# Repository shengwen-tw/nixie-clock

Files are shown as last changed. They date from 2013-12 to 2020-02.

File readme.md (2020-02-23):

## Nixie Clock
* Author : Shengwen Cheng (shengwen1997.tw@gmail.com)
* Special thanks : 張世昌, 楊宗凡, 施翰誠, 周明哲, 王尹辰, 陳冠宇
* Microcontroller : Arduino (ATMega328p-au)

## Introduction

A Russian IN-14 Nixie tube clock which support time display, alram and mp3 playing function 

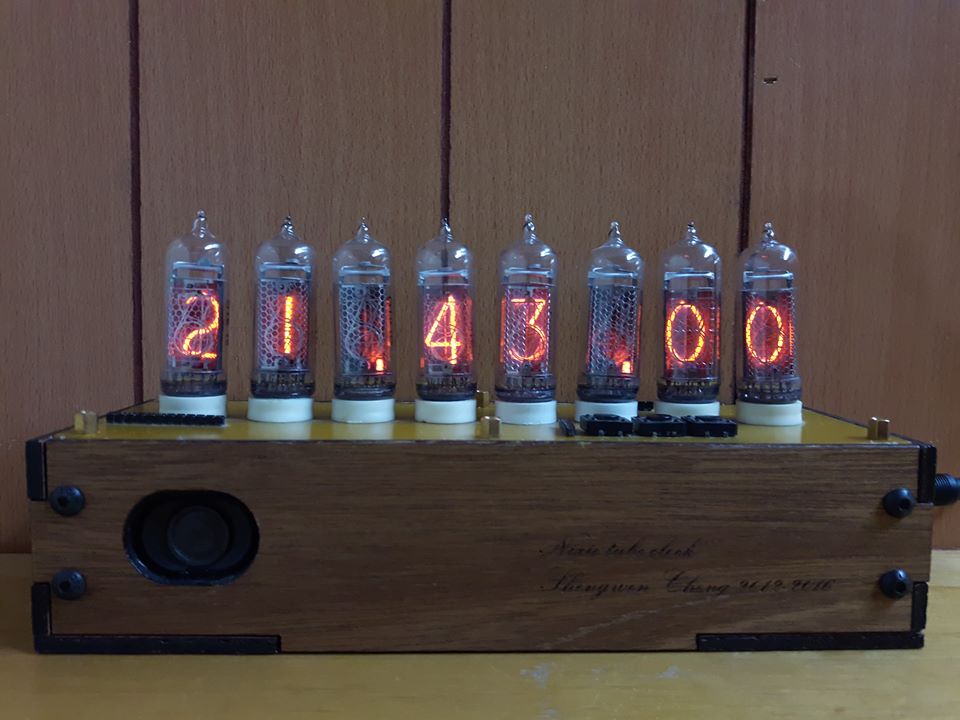
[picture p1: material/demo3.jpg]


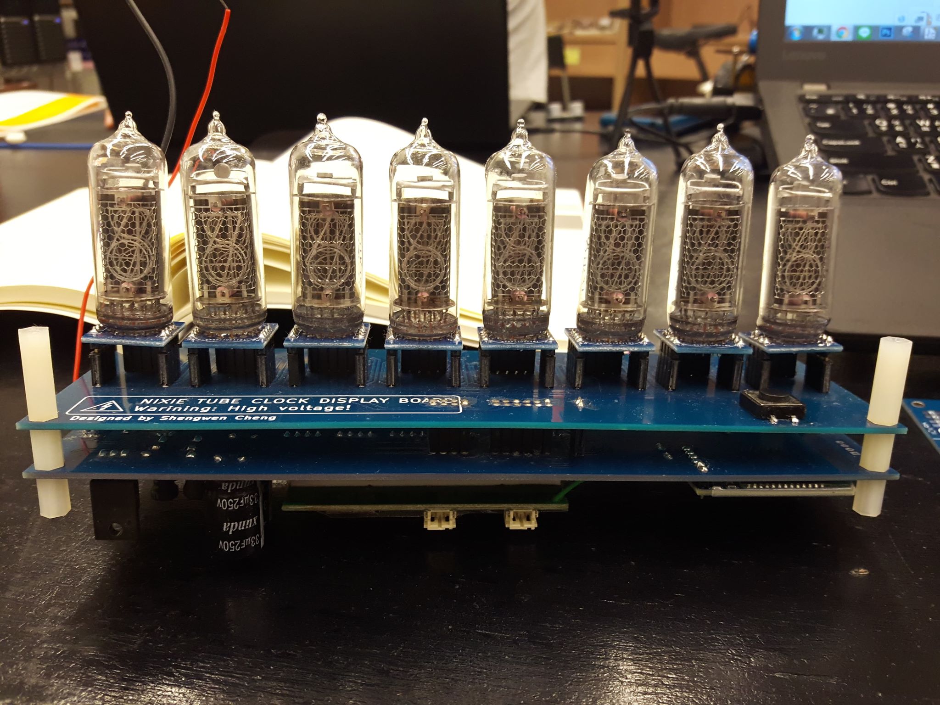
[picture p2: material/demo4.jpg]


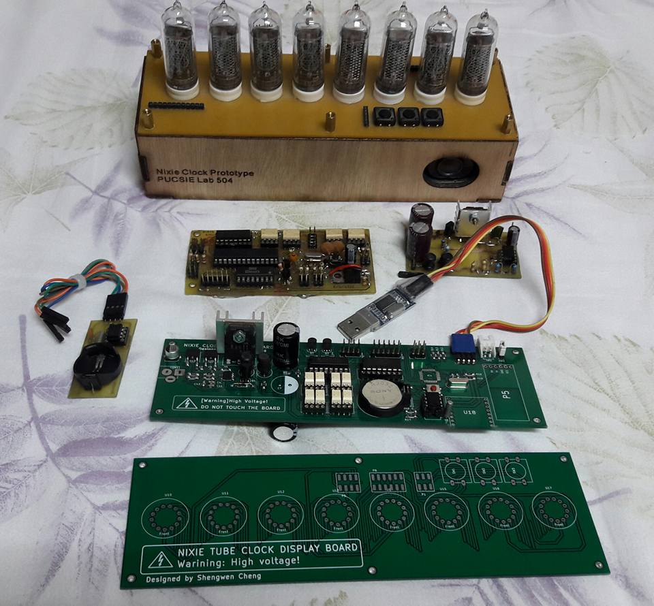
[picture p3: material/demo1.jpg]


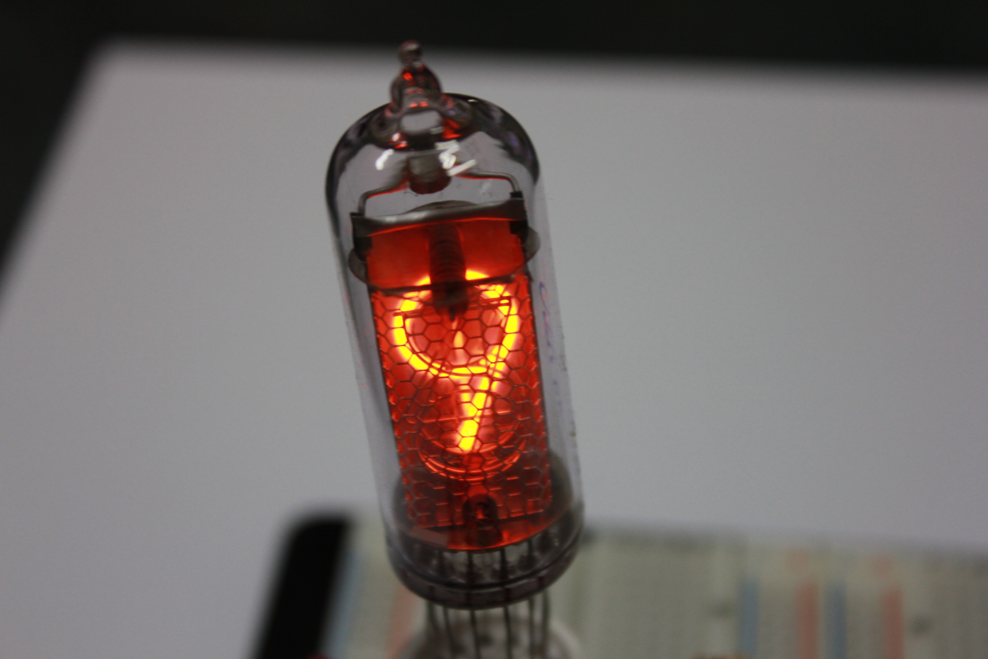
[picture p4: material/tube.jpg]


## Firmware dependencies

You must install the following arduino libraries before compiling the firmware (find the zip in firmware directory)

* DFPlayer driver (a modified version of AltSoftwareSerial)
* RTC and Time library

## USBasp driver

1. Download Zadig

2. Select **Options/List All Devices**

3. Select **USBasp**

4. Select **libusbK**

5. Click **Replace Driver**

## Circuit files

The hardware was designed under Kicad 4, any previous version may not work properly.

## BOM
read the [BOM.md](https://github.com/shengwen1997/Nixie-Clock/blob/master/BOM.md) for detailed information

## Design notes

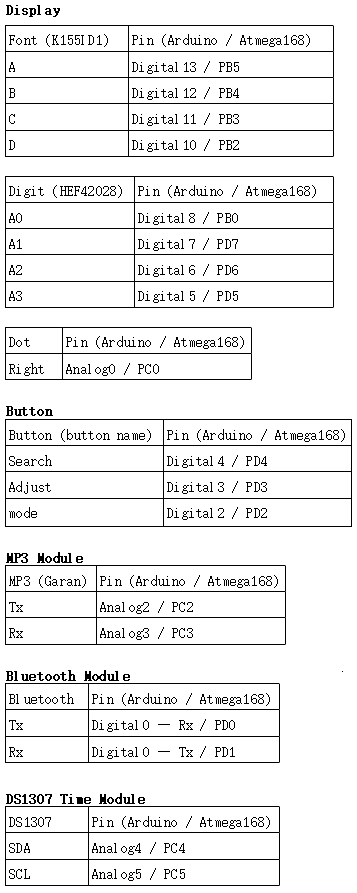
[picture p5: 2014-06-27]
material/pinout.png

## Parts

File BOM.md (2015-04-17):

Power Supply Board
======================

**Resistor**

0.5 ohm * 2

620 ohm * 3

760 ohm * 1

1k ohm * 2

100k ohm * 1

**Electrolytic capacitor**

100uf/16v * 1

33uf/250v * 2

**Mylar capacitor**

1500pf * 1

**Inductor**

22 uf * 1

220 uh * 1

**Diode**

1N4148 * 1

FR157 * 1

**IC**

MC34063A * 1

*BJT**

2SB647(PNP) * 1

**MOSFET**

2SK2611(N-Type) * 1

Display Board
======================

**Nixie tube**

IN-14 * 8

Control Board
======================

**Resistor**

330 ohm * 6

1.8k ohm * 2

4.7k ohm *2

10k ohm * 1

30k ohm * 1

**Electrolytic capacitor**

100uf/16v * 

**Ceramic capacitors**

0.1uf * 2

22pf * 2

**IC**

LM7805 * 1

ATMega328p * 1

TLP521 * 4

HEF428 * 1

K155ID1 * 1

**BJT**

MPSA9(PNP) * 3

**Quartz crystal oscillator**

16MHZ * 1

**Switch**

(2p, 6x6x4.3mm) * 1

**Pin**

(1 * 2 array) * 5

(1 * 4 array) * 2

(2 * 4 array) * 1

(2 * 6 array) * 1

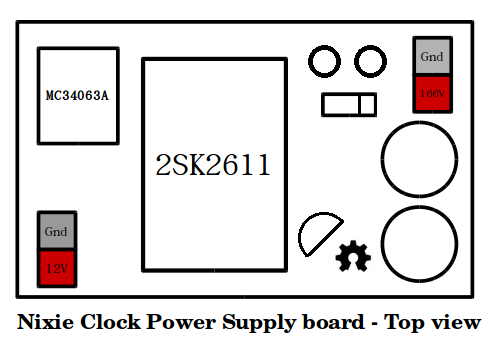
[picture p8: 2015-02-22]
material/power_supply_board.png

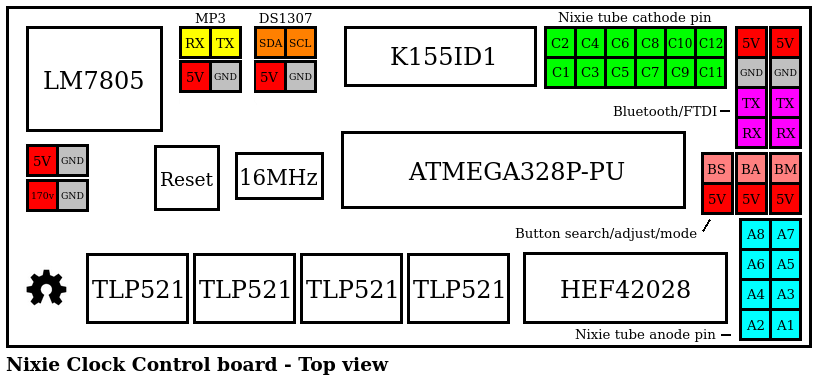
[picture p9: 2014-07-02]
material/control_board.png

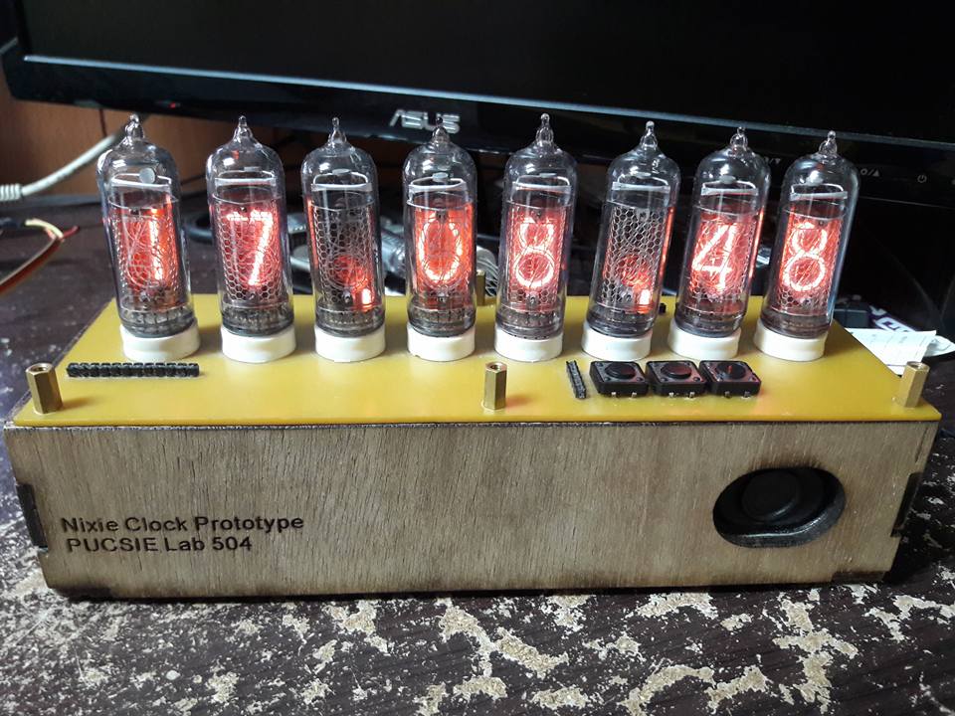
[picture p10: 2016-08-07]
material/demo2.jpg

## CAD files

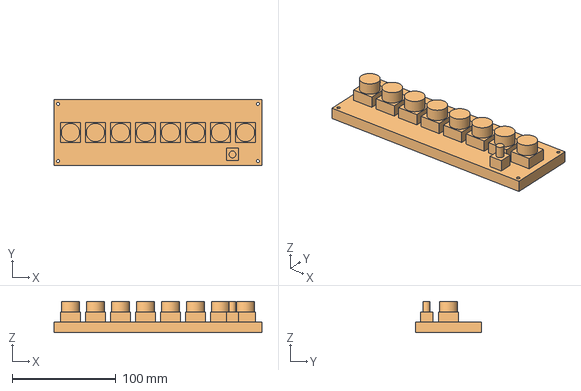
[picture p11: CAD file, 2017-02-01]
cad/obsoleted/cad.fcstd
200.0 x 63.0 x 30.0 mm

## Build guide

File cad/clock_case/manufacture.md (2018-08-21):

## Manufacture note

The case was designed by using **SketchUp**, a transformation from 3D to 2D is needed.

You can cut the case with laser cutter then assemble it with super glue and screws.

## Materials

4mm Plywood

M3 12mm SHCS * 8

M4 10mm SHCS * 8

M3 10mm female plastic pillar (top layer) * 4

M3 10mm male plastic pillar (second layer) * 4

M3 20mm female plastic pillar (bottom layer) * 4

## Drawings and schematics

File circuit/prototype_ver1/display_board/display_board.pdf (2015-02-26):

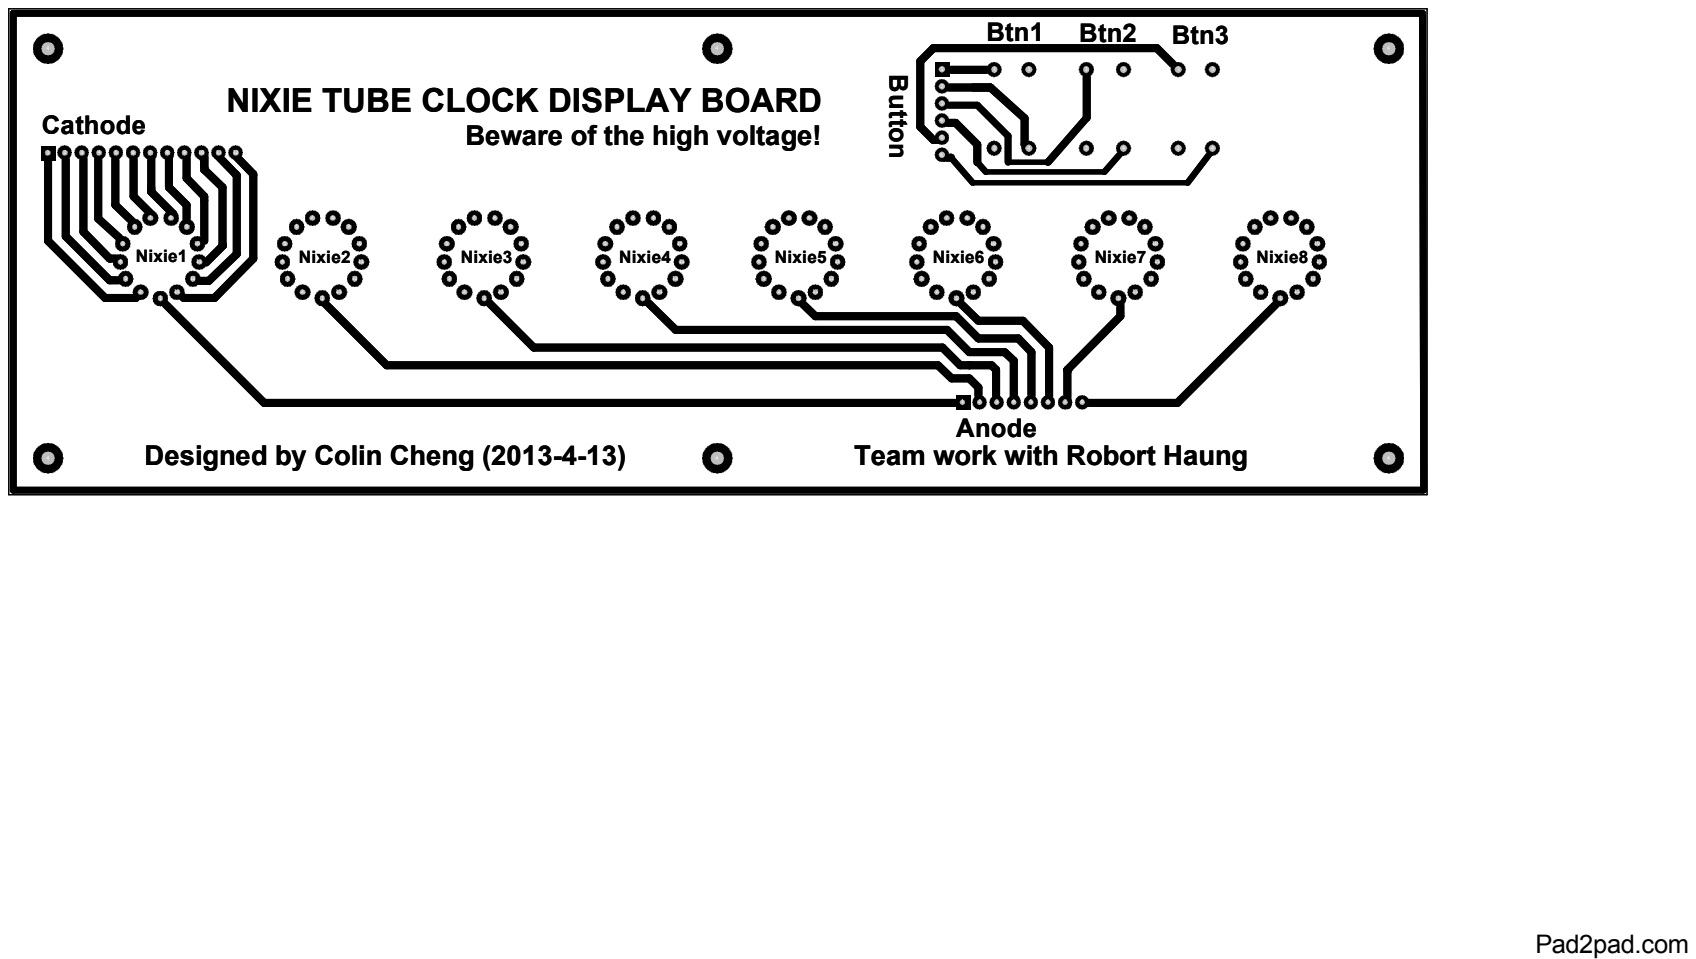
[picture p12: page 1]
Pad2pad.com; Designed by Colin Cheng (2013-4-13); Team work with Robort Haung; Btn1; Btn2; Btn3; B utto; Anode; Cathode; Nixie1; Nixie2; Nixie3; Nixie4; Nixie5; Nixie6; Nixie7; Nixie8

NIXIE TUBE CLOCK DISPLAY BOARD

Beware of the high voltage!

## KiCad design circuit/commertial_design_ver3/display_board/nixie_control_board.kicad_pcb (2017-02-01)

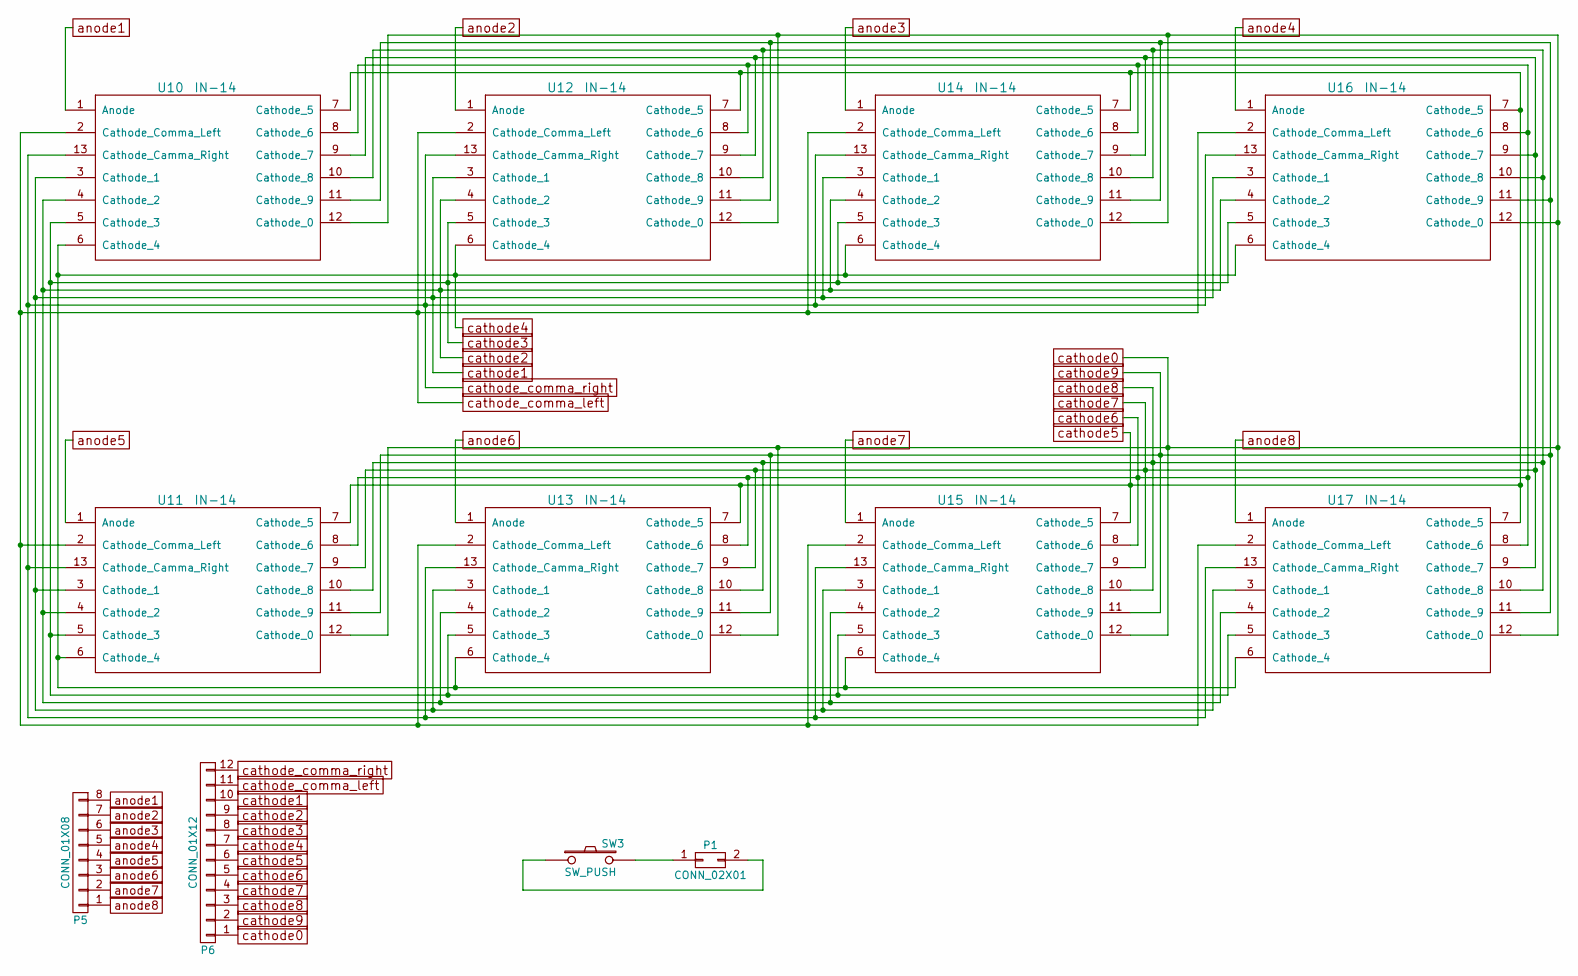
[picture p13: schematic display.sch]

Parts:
P1: CONN_02X01; Pin_Header_Straight_2x01
P5: CONN_01X08; Pin_Header_Straight_2x04
P6: CONN_01X12; Pin_Header_Straight_2x06
SW3: SW_PUSH; SW_PUSH-12mm
U10, U11, U12, U13, U14, U15, U16, U17: IN-14

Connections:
unnamed: P1.1, SW3.2
unnamed: P1.2, SW3.1
anode1: P5.8, U10.1 (Anode)
anode2: P5.7, U12.1 (Anode)
anode3: P5.6, U14.1 (Anode)
anode4: P5.5, U16.1 (Anode)
anode5: P5.4, U11.1 (Anode)
anode6: P5.3, U13.1 (Anode)
anode7: P5.2, U15.1 (Anode)
anode8: P5.1, U17.1 (Anode)
cathode0: P6.1, U10.12 (Cathode_0), U11.12 (Cathode_0), U12.12 (Cathode_0), U13.12 (Cathode_0), U14.12 (Cathode_0), U15.12 (Cathode_0), U16.12 (Cathode_0), U17.12 (Cathode_0)
cathode1: P6.10, U10.3 (Cathode_1), U11.3 (Cathode_1), U12.3 (Cathode_1), U13.3 (Cathode_1), U14.3 (Cathode_1), U15.3 (Cathode_1), U16.3 (Cathode_1), U17.3 (Cathode_1)
cathode2: P6.9, U10.4 (Cathode_2), U11.4 (Cathode_2), U12.4 (Cathode_2), U13.4 (Cathode_2), U14.4 (Cathode_2), U15.4 (Cathode_2), U16.4 (Cathode_2), U17.4 (Cathode_2)
cathode3: P6.8, U10.5 (Cathode_3), U11.5 (Cathode_3), U12.5 (Cathode_3), U13.5 (Cathode_3), U14.5 (Cathode_3), U15.5 (Cathode_3), U16.5 (Cathode_3), U17.5 (Cathode_3)
cathode4: P6.7, U10.6 (Cathode_4), U11.6 (Cathode_4), U12.6 (Cathode_4), U13.6 (Cathode_4), U14.6 (Cathode_4), U15.6 (Cathode_4), U16.6 (Cathode_4), U17.6 (Cathode_4)
cathode5: P6.6, U10.7 (Cathode_5), U11.7 (Cathode_5), U12.7 (Cathode_5), U13.7 (Cathode_5), U14.7 (Cathode_5), U15.7 (Cathode_5), U16.7 (Cathode_5), U17.7 (Cathode_5)
cathode6: P6.5, U10.8 (Cathode_6), U11.8 (Cathode_6), U12.8 (Cathode_6), U13.8 (Cathode_6), U14.8 (Cathode_6), U15.8 (Cathode_6), U16.8 (Cathode_6), U17.8 (Cathode_6)
cathode7: P6.4, U10.9 (Cathode_7), U11.9 (Cathode_7), U12.9 (Cathode_7), U13.9 (Cathode_7), U14.9 (Cathode_7), U15.9 (Cathode_7), U16.9 (Cathode_7), U17.9 (Cathode_7)
cathode8: P6.3, U10.10 (Cathode_8), U11.10 (Cathode_8), U12.10 (Cathode_8), U13.10 (Cathode_8), U14.10 (Cathode_8), U15.10 (Cathode_8), U16.10 (Cathode_8), U17.10 (Cathode_8)
cathode9: P6.2, U10.11 (Cathode_9), U11.11 (Cathode_9), U12.11 (Cathode_9), U13.11 (Cathode_9), U14.11 (Cathode_9), U15.11 (Cathode_9), U16.11 (Cathode_9), U17.11 (Cathode_9)
cathode_comma_left: P6.11, U10.2 (Cathode_Comma_Left), U11.2 (Cathode_Comma_Left), U12.2 (Cathode_Comma_Left), U13.2 (Cathode_Comma_Left), U14.2 (Cathode_Comma_Left), U15.2 (Cathode_Comma_Left), U16.2 (Cathode_Comma_Left), U17.2 (Cathode_Comma_Left)
cathode_comma_right: P6.12, U10.13 (Cathode_Camma_Right), U11.13 (Cathode_Camma_Right), U12.13 (Cathode_Camma_Right), U13.13 (Cathode_Camma_Right), U14.13 (Cathode_Camma_Right), U15.13 (Cathode_Camma_Right), U16.13 (Cathode_Camma_Right), U17.13 (Cathode_Camma_Right)

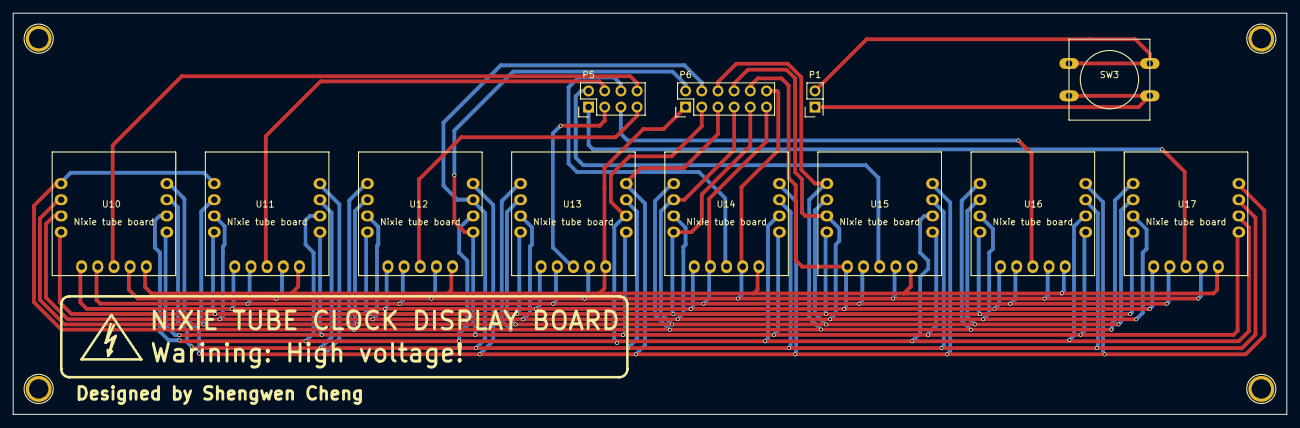
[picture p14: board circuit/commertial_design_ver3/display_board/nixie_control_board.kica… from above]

Board: 2 copper layers, 200.0 x 63.0 mm, 13 parts (0 on the bottom side), 22 nets.

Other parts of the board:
e REF**: 1pin

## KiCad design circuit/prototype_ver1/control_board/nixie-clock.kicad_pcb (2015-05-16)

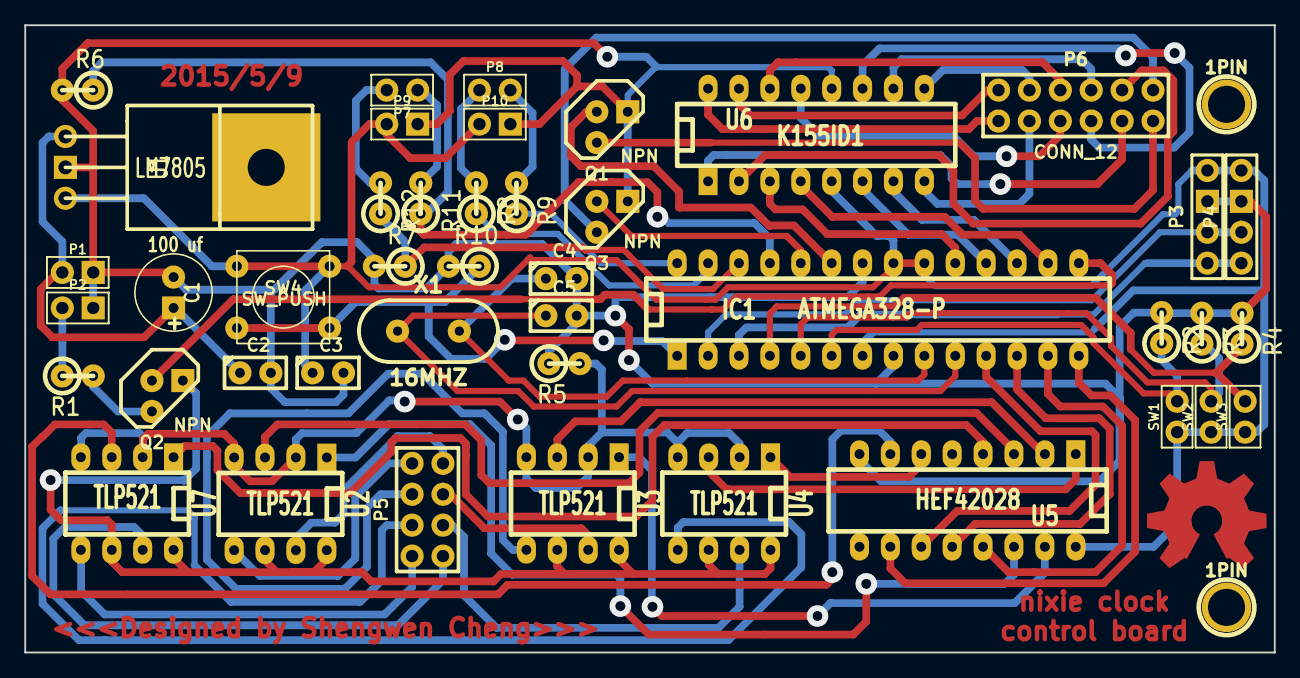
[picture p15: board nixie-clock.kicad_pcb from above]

Board: 2 copper layers, 102.7 x 51.6 mm, 46 parts (0 on the bottom side), 62 nets.

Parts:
1PIN, 1PIN#2: P***; 1pin
C1: 100 uf; C1V7
C2, C3: 0.1 uf; C1
C4, C5: 22pf; C1
IC1: ATMEGA328-P; DIP-28__300_ELL
OSHW_COPPER_10MM: VAL**; OSHW_COPPER_10MM
P1, P2, P7, P8, P9, P10: CONN_2; PIN_ARRAY_2X1
P3, P4: CONN_4; PIN_ARRAY_4x1
P5: CONN_8; pin_array_4x2
P6: CONN_12; pin_array_6x2
Q1, Q2, Q3: NPN; TO92
R1: 100k ohm; R1
R2, R3, R4, R5, R6, R7: 330ohm; R1
R8, R9: 4.7k ohm; R1
R10: 10k ohm; R1
R11, R12: 1.8kohm; R1
SW1, SW2, SW3: SW_PUSH; PIN_ARRAY_2X1
SW4: SW_PUSH; SW_PUSH_SMALL
U1: LM7805; LM78XX
U2, U3, U4, U7: TLP521; DIP-8__300_ELL
U5: HEF42028; DIP-16__300_ELL
U6: K155ID1; DIP-16__300_ELL
X1: 16MHZ; HC-49V

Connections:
5V: C3.1, IC1.7, IC1.20, IC1.21, P3.4, P4.4, P9.1, P10.1, SW1.1, SW2.1, SW3.1, SW4.1, U1.VO, U5.16, U6.5
170V: Q2.3, R1.2
Adjust button: IC1.5, R3.1, SW2.2
Bluetooth/FTDI Rx: IC1.3, P3.1, P4.1
Bluetooth/FTDI Tx: IC1.2, P3.2, P4.2
Brightness: IC1.15, Q2.2
Crystal1: C4.1, IC1.9, X1.2
Crystal2: C5.1, IC1.10, X1.1
Digit A0: IC1.14, U5.10
Digit A1: IC1.13, U5.13
Digit A2: IC1.12, U5.12
Digit A3: IC1.11, U5.11
Font A: IC1.19, U6.3
Font B: IC1.18, U6.6
Font C: IC1.17, U6.7
Font D: IC1.16, U6.4
GND: C1.2, C2.2, C3.2, C4.2, C5.2, IC1.8, IC1.22, P1.2, P2.2, P3.3, P4.3, P9.2, P10.2, Q1.1, Q3.1, R2.2, R3.2, R4.2, R5.1, R6.2, R7.2, R10.2, U1.GND, U5.8, U6.12
I2C SCL: IC1.28, R9.1
I2C SDA: IC1.27, R8.1
Left dot: IC1.24, Q3.2
MP3 Rx: IC1.26, R7.1, R12.1
MP3 Tx: IC1.25, R6.1, R11.1
Mode button: IC1.4, R4.1, SW3.2
unnamed: C1.1, C2.1, P1.1, U1.VI
unnamed: P2.1, R1.1
unnamed: P5.1, U7.7
unnamed: P5.2, U7.5
unnamed: P5.3, U4.7
unnamed: P5.4, U4.5
unnamed: P5.5, U3.7
unnamed: P5.6, U3.5
unnamed: P5.7, U2.7
unnamed: P5.8, U2.5
unnamed: P6.1, U6.16
unnamed: P6.2, U6.15
unnamed: P6.3, U6.8
unnamed: P6.4, U6.9
unnamed: P6.5, U6.13
unnamed: P6.6, U6.14
unnamed: P6.7, U6.11
unnamed: P6.8, U6.10
unnamed: P6.9, U6.1
unnamed: P6.10, U6.2
unnamed: P6.11, Q1.3
unnamed: P6.12, Q3.3
unnamed: P7.1, R11.2
unnamed: P7.2, R12.2
unnamed: P8.1, R8.2
unnamed: P8.2, R9.2
unnamed: Q2.1, U2.6, U2.8, U3.6, U3.8, U4.6, U4.8, U7.6, U7.8
unnamed: R5.2, U2.2, U2.4, U3.2, U3.4, U4.2, U4.4, U7.2, U7.4
unnamed: U2.1, U5.14
unnamed: U2.3, U5.3
unnamed: U3.1, U5.15
unnamed: U3.3, U5.2
unnamed: U4.1, U5.6
unnamed: U4.3, U5.1
unnamed: U5.4, U7.1
unnamed: U5.7, U7.3
Reset: IC1.1, R10.1, SW4.2
Right dot: IC1.23, Q1.2
Search button: IC1.6, R2.1, SW1.2

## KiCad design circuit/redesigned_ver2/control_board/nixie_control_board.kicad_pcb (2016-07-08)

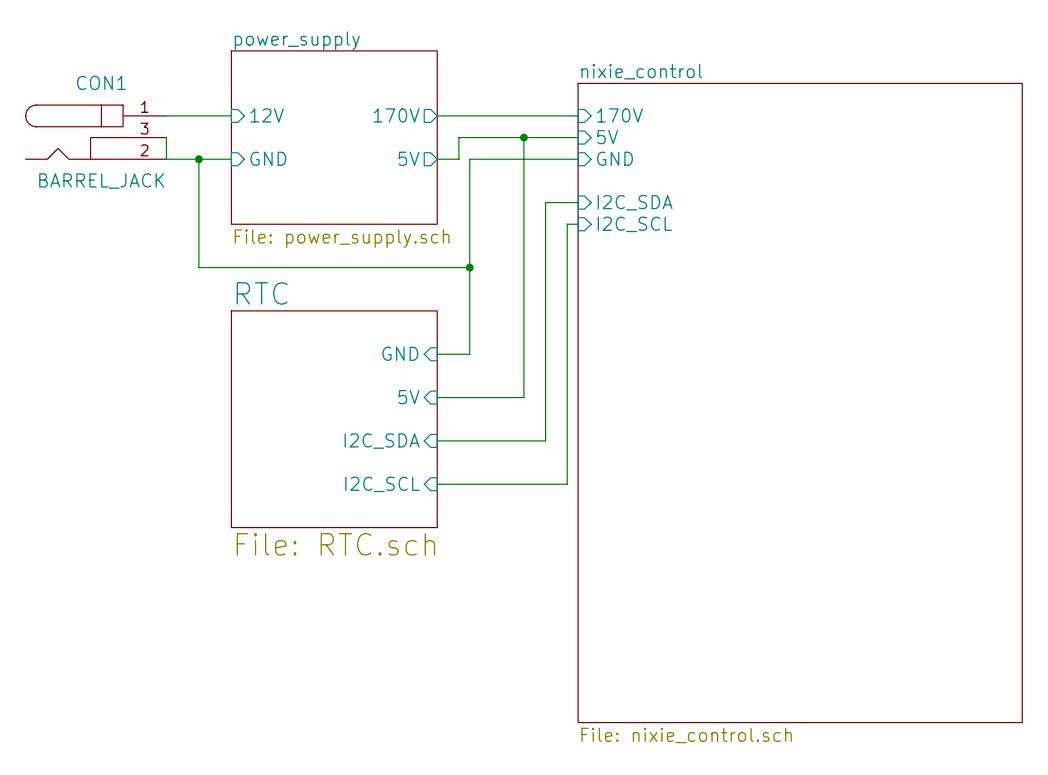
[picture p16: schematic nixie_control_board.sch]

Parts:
CON1: BARREL_JACK; JACK_ALIM

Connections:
/RTC/GND: CON1.2, CON1.3; also elsewhere on the board
/power_supply/12V: CON1.1; also elsewhere on the board

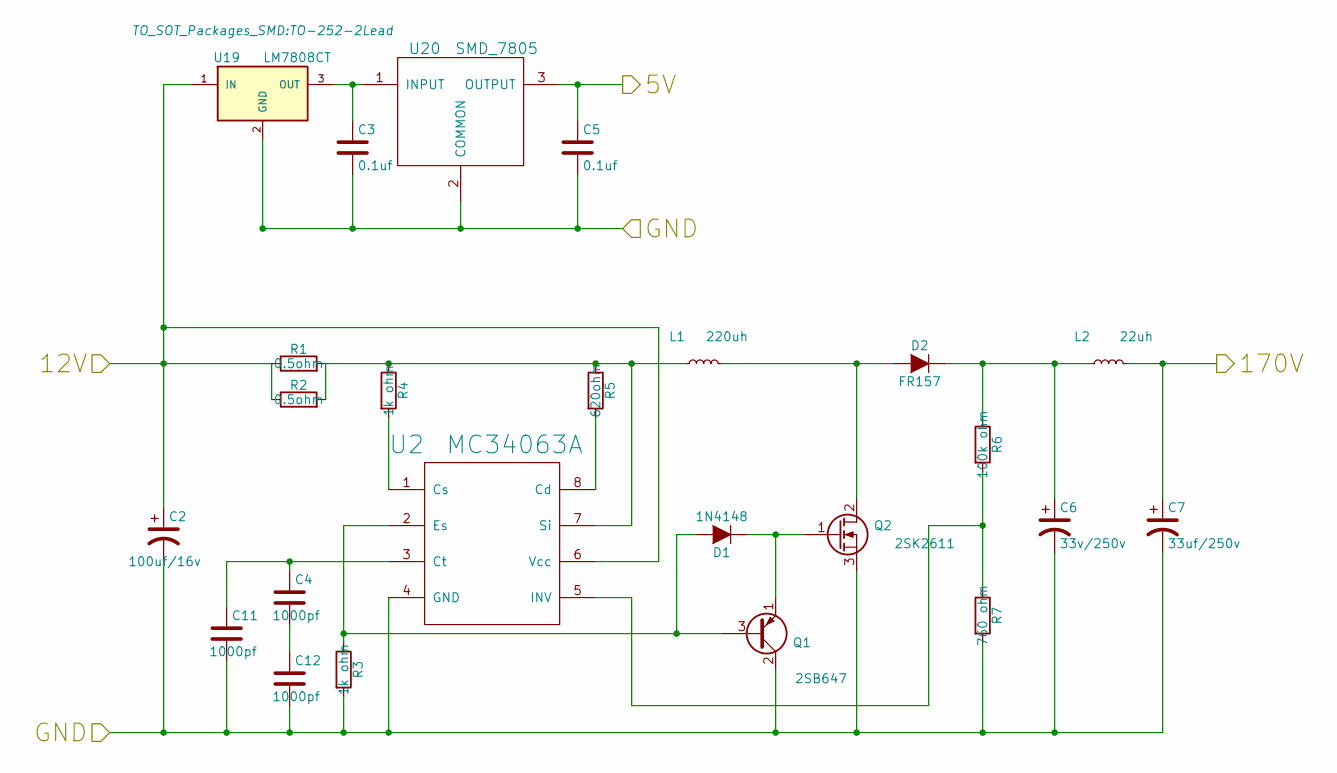
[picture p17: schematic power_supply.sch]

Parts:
C2: 100uf/16v; c_elec_6.3x5.3
C3, C5: 0.1uf; C_0805_HandSoldering
C4, C11, C12: 1000pf; C_0805_HandSoldering
C6: 33v/250v; C_Radial_D13_L21_P5
C7: 33uf/250v; C_Radial_D13_L21_P5
D1: 1N4148; Diode_DO-35_SOD27_Horizontal_RM10
D2: FR157; Diode_DO-35_SOD27_Horizontal_RM10
L1: 220uh; INDUCTOR_V
L2: 22uh; INDUCTOR_V
Q1: 2SB647; TO-92_Inline_Narrow_Oval
Q2: 2SK2611; TO-247_Vertical_Neutral123
R1, R2: 0.5ohm; R_1206_HandSoldering
R3, R4: 1k ohm; R_1206_HandSoldering
R5: 620ohm; R_1206_HandSoldering
R6: 100k ohm; R_1206_HandSoldering
R7: 760 ohm; R_1206_HandSoldering
U2: MC34063A; SO-8
U19: LM7808CT; TO-252-2Lead
U20: SMD_7805; TO-252-2Lead

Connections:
/RTC/5V: C5.1, U20.3 (OUTPUT); also elsewhere on the board
/RTC/GND: C2.2, C3.2, C5.2, C6.2, C7.2, C11.2, C12.2, Q1.2 (C), Q2.3 (S), R3.2, R7.2, U2.4 (GND), U19.2 (GND), U20.2 (COMMON); also elsewhere on the board
/nixie_control/170V: C7.1, L2.2; also elsewhere on the board
/power_supply/12V: C2.1, R1.1, R2.1, U2.6 (Vcc), U19.1 (IN); also elsewhere on the board
unnamed: C3.1, U19.3 (OUT), U20.1 (INPUT)
unnamed: C6.1, D2.1 (K), L2.1, R6.1
unnamed: C4.1, C11.1, U2.3 (Ct)
unnamed: C4.2, C12.1
unnamed: D1.1 (K), Q1.1 (E), Q2.1 (G)
unnamed: D1.2 (A), Q1.3 (B), R3.1, U2.2 (Es)
unnamed: D2.2 (A), L1.2, Q2.2 (D)
unnamed: L1.1, R1.2, R2.2, R4.1, R5.1, U2.7 (Si)
unnamed: R4.2, U2.1 (Cs)
unnamed: R5.2, U2.8 (Cd)
unnamed: R6.2, R7.1, U2.5 (INV)

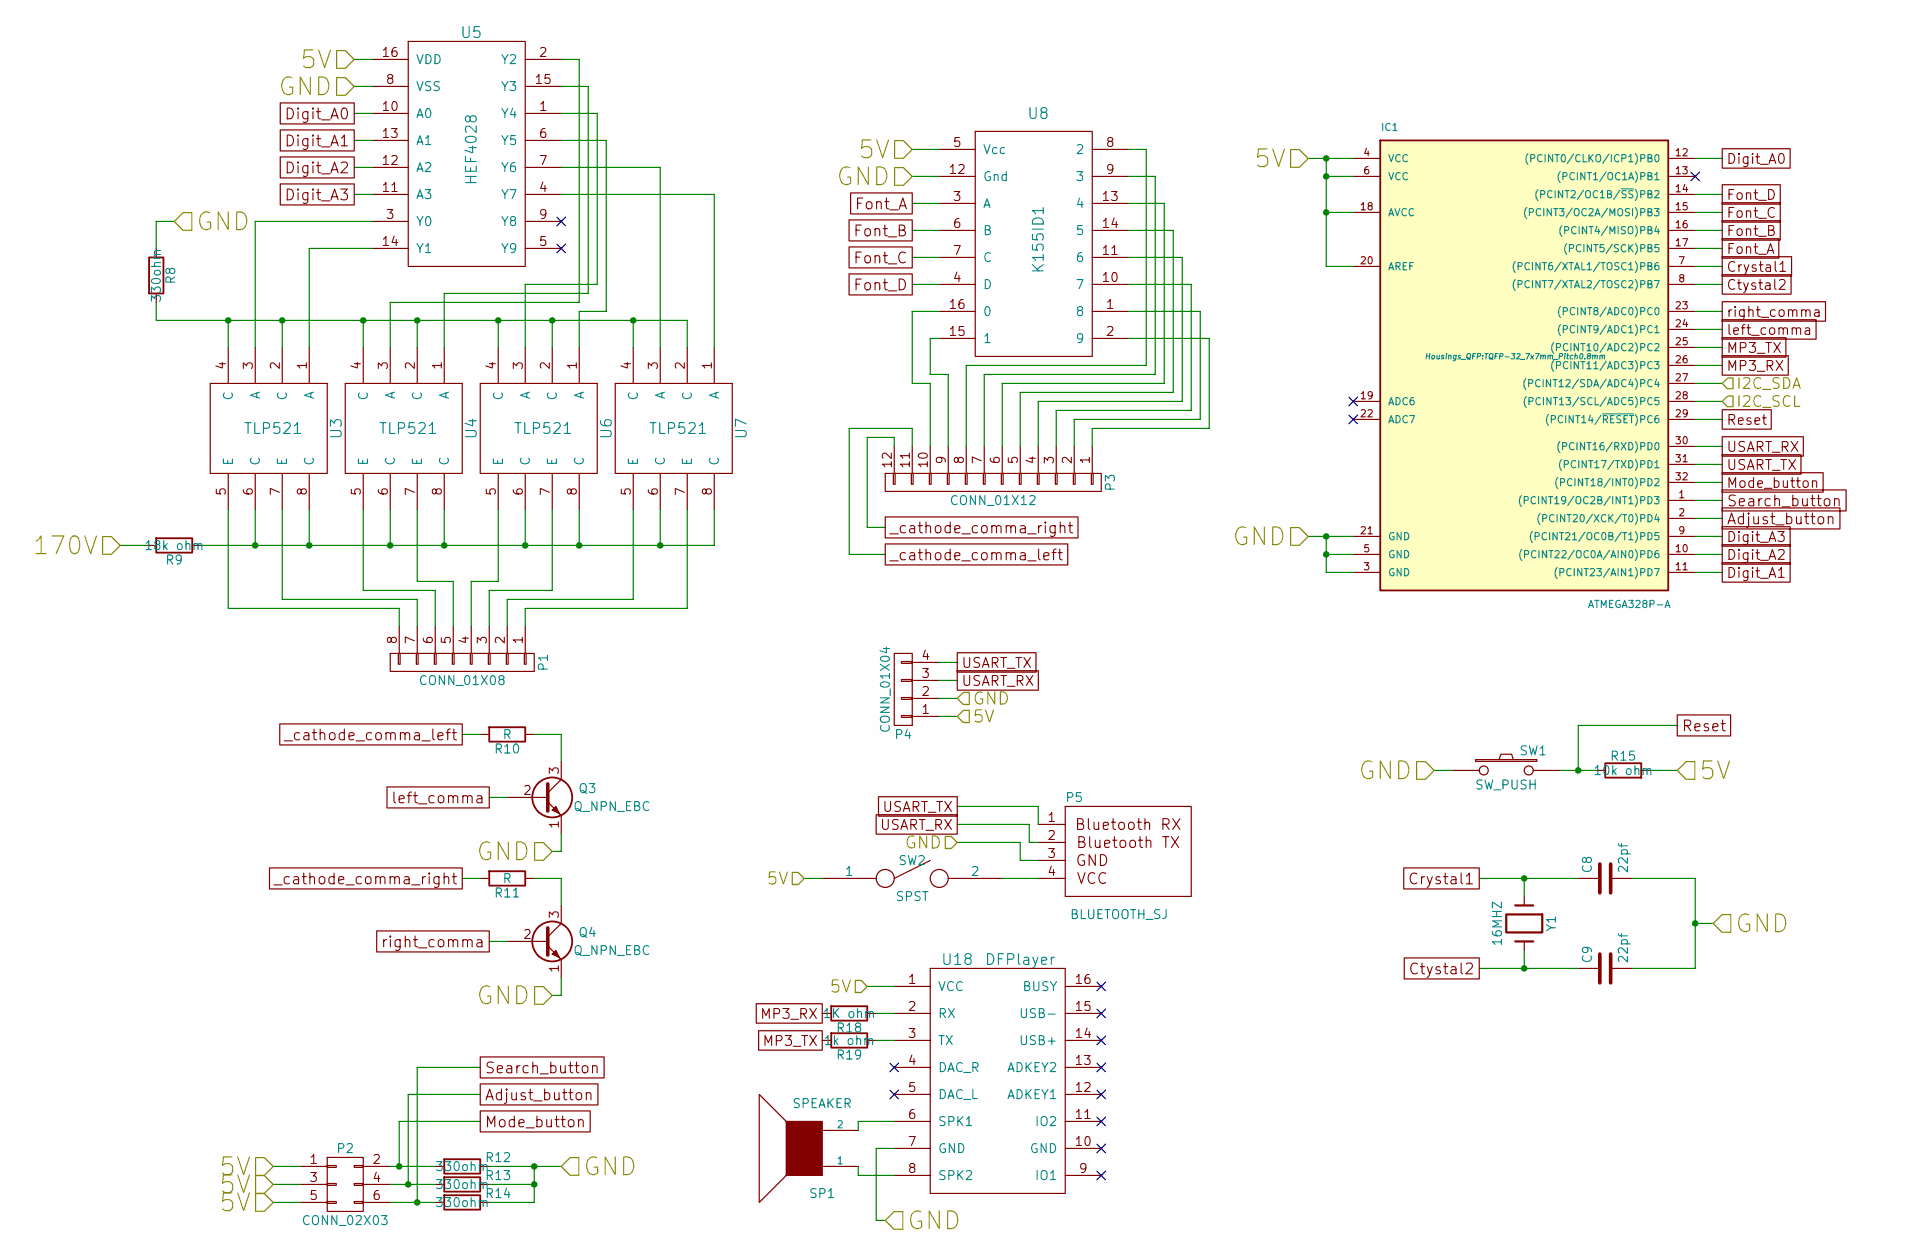
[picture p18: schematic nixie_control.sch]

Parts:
C8, C9: 22pf; C_0805_HandSoldering
IC1: ATMEGA328P-A; TQFP-32_7x7mm_Pitch0.8mm
P1: CONN_01X08; SMD_PIN_2_BY_4_REVERSE
P2: CONN_02X03; SMD_PIN_2_BY_3_REVERSE
P3: CONN_01X12; SMD_PIN_2_BY_6_REVERSE
P4: CONN_01X04; Pin_Header_Angled_1x04
P5: BLUETOOTH_SJ; HC06
Q3, Q4: Q_NPN_EBC; TO-92_Inline_Narrow_Oval
R8, R12, R13, R14: 330ohm; R_1206_HandSoldering
R9: 18k ohm; R_1206_HandSoldering
R10, R11: R; R_1206_HandSoldering
R15: 10k ohm; R_1206_HandSoldering
R18: 1K ohm; R_1206_HandSoldering
R19: 1k ohm; R_1206_HandSoldering
SP1: SPEAKER; PINHEAD1-2
SW1: SW_PUSH; SW_SPST_PTS645
SW2: SPST; Pin_Header_Straight_1x02
U3, U4, U6, U7: TLP521; DIP-8_W7.62mm
U5: HEF4028; DIP-16_W7.62mm
U8: K155ID1; DIP-16_W7.62mm
U18: DFPlayer
Y1: 16MHZ; Crystal_HC49-U_Vertical

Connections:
/RTC/5V: IC1.4 (VCC), IC1.6 (VCC), IC1.18 (AVCC), IC1.20 (AREF), P2.1, P2.3, P2.5, P4.1, R15.2, SW2.1, U5.16 (VDD), U8.5 (Vcc), U18.1 (VCC); also elsewhere on the board
/RTC/GND: C8.2, C9.2, IC1.3 (GND), IC1.5 (GND), IC1.21 (GND), P4.2, P5.3, Q3.1 (E), Q4.1 (E), R8.1, R12.1, R13.1, R14.1, SW1.1, U5.8 (VSS), U8.12 (Gnd), U18.7 (GND); also elsewhere on the board
/RTC/I2C_SCL: IC1.28 ((PCINT13/SCL/ADC5)PC5); also elsewhere on the board
/RTC/I2C_SDA: IC1.27 ((PCINT12/SDA/ADC4)PC4); also elsewhere on the board
/nixie_control/170V: R9.2; also elsewhere on the board
Adjust_button: IC1.2 ((PCINT20/XCK/T0)PD4), P2.4, R13.2
Crystal1: C8.1, IC1.7 ((PCINT6/XTAL1/TOSC1)PB6), Y1.1
Ctystal2: C9.1, IC1.8 ((PCINT7/XTAL2/TOSC2)PB7), Y1.2
Digit_A0: IC1.12 ((PCINT0/CLKO/ICP1)PB0), U5.10 (A0)
Digit_A1: IC1.11 ((PCINT23/AIN1)PD7), U5.13 (A1)
Digit_A2: IC1.10 ((PCINT22/OC0A/AIN0)PD6), U5.12 (A2)
Digit_A3: IC1.9 ((PCINT21/OC0B/T1)PD5), U5.11 (A3)
Font_A: IC1.17 ((PCINT5/SCK)PB5), U8.3 (A)
Font_B: IC1.16 ((PCINT4/MISO)PB4), U8.6 (B)
Font_C: IC1.15 ((PCINT3/OC2A/MOSI)PB3), U8.7 (C)
Font_D: IC1.14 ((PCINT2/OC1B/~SS~)PB2), U8.4 (D)
MP3_RX: IC1.26 ((PCINT11/ADC3)PC3), R18.2
MP3_TX: IC1.25 ((PCINT10/ADC2)PC2), R19.2
Mode_button: IC1.32 ((PCINT18/INT0)PD2), P2.2, R12.2
unnamed: P1.1, U7.7 (E)
unnamed: P1.2, U7.5 (E)
unnamed: P1.3, U6.7 (E)
unnamed: P1.4, U6.5 (E)
unnamed: P1.5, U4.7 (E)
unnamed: P1.6, U4.5 (E)
unnamed: P1.7, U3.7 (E)
unnamed: P1.8, U3.5 (E)
unnamed: P3.1, U8.2 (9)
unnamed: P3.2, U8.1 (8)
unnamed: P3.3, U8.10 (7)
unnamed: P3.4, U8.11 (6)
unnamed: P3.5, U8.14 (5)
unnamed: P3.6, U8.13 (4)
unnamed: P3.7, U8.9 (3)
unnamed: P3.8, U8.8 (2)
unnamed: P3.9, U8.15 (1)
unnamed: P3.10, U8.16 (0)
unnamed: P5.4, SW2.2
unnamed: Q3.3 (C), R10.1
unnamed: Q4.3 (C), R11.1
unnamed: R8.2, U3.2 (C), U3.4 (C), U4.2 (C), U4.4 (C), U6.2 (C), U6.4 (C), U7.2 (C), U7.4 (C)
unnamed: R9.1, U3.6 (C), U3.8 (C), U4.6 (C), U4.8 (C), U6.6 (C), U6.8 (C), U7.6 (C), U7.8 (C)
unnamed: R18.1, U18.2 (RX)
unnamed: R19.1, U18.3 (TX)
unnamed: SP1.1, U18.8 (SPK2)
unnamed: SP1.2, U18.6 (SPK1)
unnamed: U3.1 (A), U5.14 (Y1)
unnamed: U3.3 (A), U5.3 (Y0)
unnamed: U4.1 (A), U5.15 (Y3)
unnamed: U4.3 (A), U5.2 (Y2)
unnamed: U5.1 (Y4), U6.3 (A)
unnamed: U5.4 (Y7), U7.1 (A)
unnamed: U5.6 (Y5), U6.1 (A)
unnamed: U5.7 (Y6), U7.3 (A)
Reset: IC1.29 ((PCINT14/~RESET~)PC6), R15.1, SW1.2
Search_button: IC1.1 ((PCINT19/OC2B/INT1)PD3), P2.6, R14.2
USART_RX: IC1.30 ((PCINT16/RXD)PD0), P4.3, P5.2
USART_TX: IC1.31 ((PCINT17/TXD)PD1), P4.4, P5.1 (BLUETOOTH_RX)
_cathode_comma_left: P3.11, R10.2
_cathode_comma_right: P3.12, R11.2
left_comma: IC1.24 ((PCINT9/ADC1)PC1), Q3.2 (B)
right_comma: IC1.23 ((PCINT8/ADC0)PC0), Q4.2 (B)

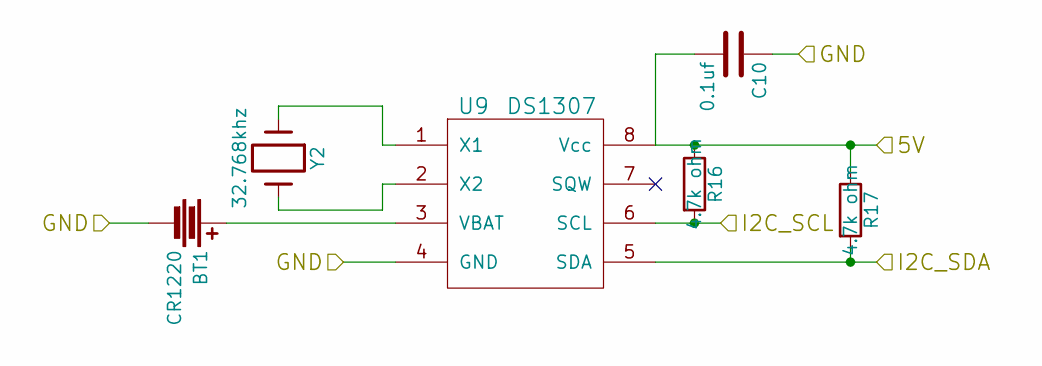
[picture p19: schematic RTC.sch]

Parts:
BT1: CR1220; CR2032H
C10: 0.1uf; C_0805_HandSoldering
R16, R17: 4.7k ohm; R_1206_HandSoldering
U9: DS1307; DIP-8_W7.62mm
Y2: 32.768khz; Crystal_Round_Vertical_2mm

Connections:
/RTC/5V: C10.2, R16.1, R17.1, U9.8 (Vcc); also elsewhere on the board
/RTC/GND: BT1.2, C10.1, U9.4 (GND); also elsewhere on the board
/RTC/I2C_SCL: R16.2, U9.6 (SCL); also elsewhere on the board
/RTC/I2C_SDA: R17.2, U9.5 (SDA); also elsewhere on the board
unnamed: BT1.1, U9.3 (VBAT)
unnamed: U9.1 (X1), Y2.1
unnamed: U9.2 (X2), Y2.2

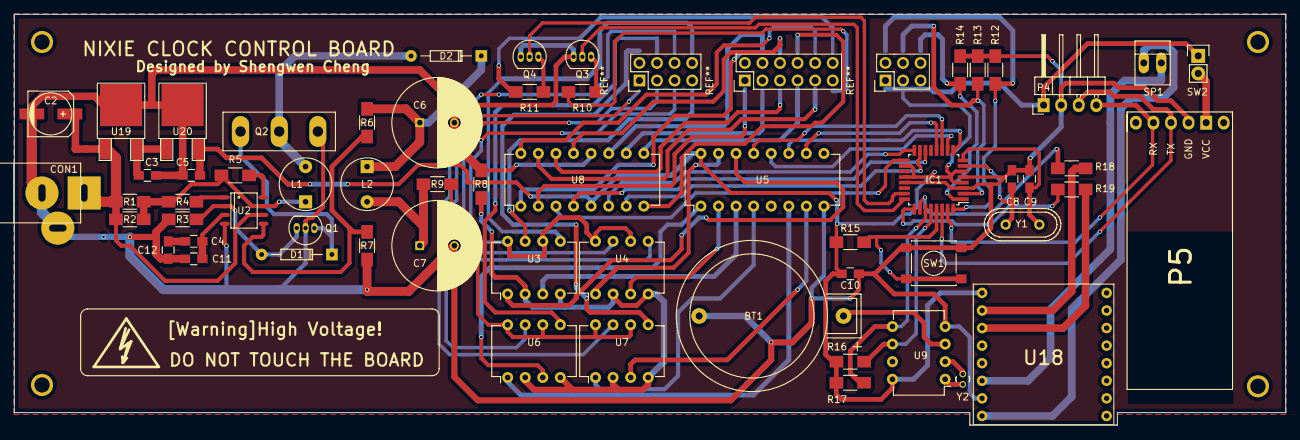
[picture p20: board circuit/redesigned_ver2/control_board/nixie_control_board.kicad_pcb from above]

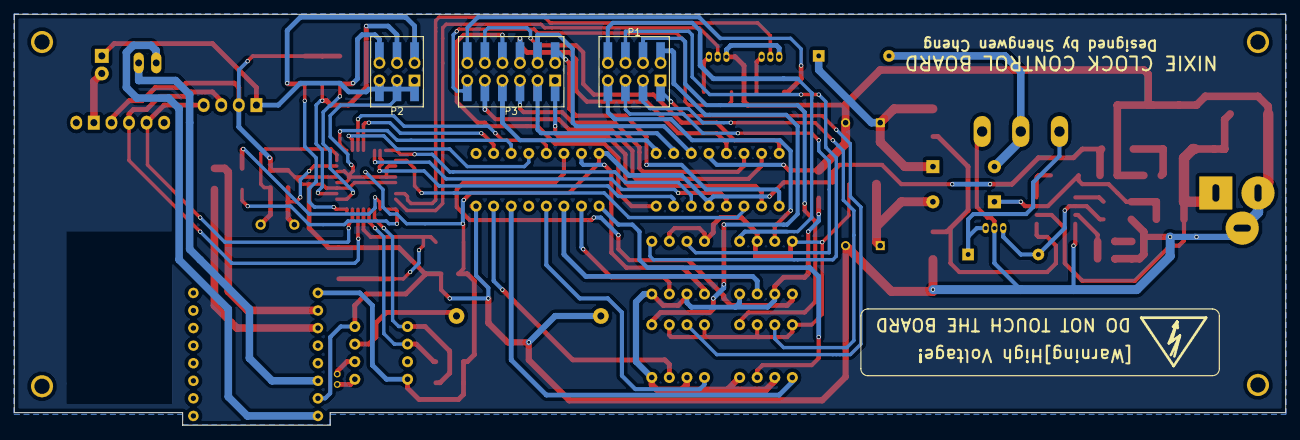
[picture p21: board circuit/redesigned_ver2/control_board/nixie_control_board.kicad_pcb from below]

Board: 2 copper layers, 183.8 x 59.4 mm, 62 parts (3 on the bottom side), 77 nets.

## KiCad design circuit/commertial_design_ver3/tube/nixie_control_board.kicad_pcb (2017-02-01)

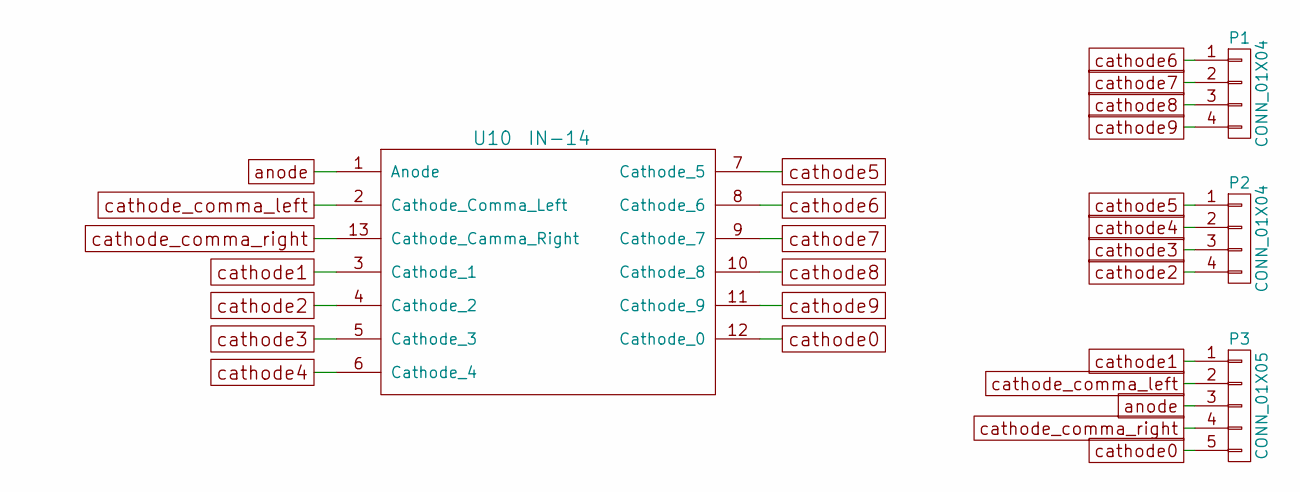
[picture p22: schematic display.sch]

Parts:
P1, P2: CONN_01X04; Pin_Header_Straight_1x04
P3: CONN_01X05; Pin_Header_Straight_1x05
U10: IN-14

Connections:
anode: P3.3, U10.1 (Anode)
cathode0: P3.5, U10.12 (Cathode_0)
cathode1: P3.1, U10.3 (Cathode_1)
cathode2: P2.4, U10.4 (Cathode_2)
cathode3: P2.3, U10.5 (Cathode_3)
cathode4: P2.2, U10.6 (Cathode_4)
cathode5: P2.1, U10.7 (Cathode_5)
cathode6: P1.1, U10.8 (Cathode_6)
cathode7: P1.2, U10.9 (Cathode_7)
cathode8: P1.3, U10.10 (Cathode_8)
cathode9: P1.4, U10.11 (Cathode_9)
cathode_comma_left: P3.2, U10.2 (Cathode_Comma_Left)
cathode_comma_right: P3.4, U10.13 (Cathode_Camma_Right)

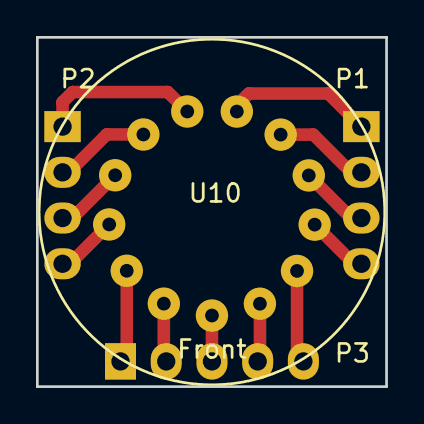
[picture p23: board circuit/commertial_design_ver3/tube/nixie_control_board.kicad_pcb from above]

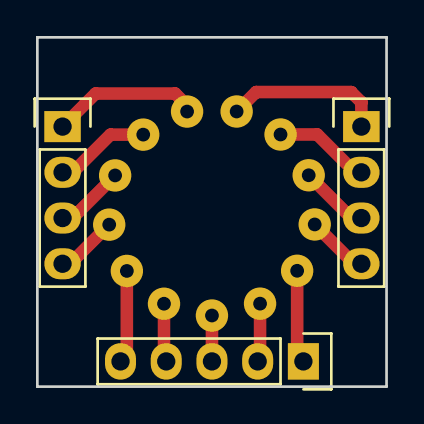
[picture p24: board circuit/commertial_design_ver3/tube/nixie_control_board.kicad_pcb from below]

Board: 2 copper layers, 19.4 x 19.4 mm, 4 parts (3 on the bottom side), 13 nets.

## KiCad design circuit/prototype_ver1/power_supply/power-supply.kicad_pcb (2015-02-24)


Board: 2 copper layers, 66.0 x 38.7 mm, 21 parts (0 on the bottom side), 12 nets.

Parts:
2SK2611: MOSFET-N; TO-247_Horizontal_FET-GDS
BT1: BATTERY; PIN_ARRAY_2X1
C1: 100uf/16v; C1V7
C2: 1500pf; C2
C3: 33v/250v; C2V10
C4: 33uf/250v; C2V10
D1: 1N4148; D3
D2: FR157; D3
L1: 220uh; PIN_ARRAY_2X1
L2: 22uh; PIN_ARRAY_2X1
OSHW_COPPER_10MM: VAL**; OSHW_COPPER_10MM
P1: CONN_2; PIN_ARRAY_2X1
PNP1: 2SB647; TO92-123
R1, R2: 1k ohm; R1
R3: 620 ohm; R1
R4: 100k ohm; R1
R5: 760 ohm; R1
R6, R7: 0.5 ohm; R1
U1: MCS34063A; DIP-8__300

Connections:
unnamed: 2SK2611.S, BT1.2, C1.2, C2.2, C3.2, C4.2, P1.2, PNP1.2, R2.2, R5.2, U1.4
unnamed: R3.2, U1.8
unnamed: C3.1, D2.2, L2.1, R4.1
unnamed: 2SK2611.D, D2.1, L1.2
unnamed: 2SK2611.G, D1.2, PNP1.1
unnamed: C4.1, L2.2, P1.1
unnamed: R1.2, U1.1
unnamed: D1.1, PNP1.3, R2.1, U1.2
unnamed: L1.1, R1.1, R3.1, R6.1, R7.1, U1.7
unnamed: R4.2, R5.1, U1.5
unnamed: BT1.1, C1.1, R6.2, R7.2, U1.6
unnamed: C2.1, U1.3

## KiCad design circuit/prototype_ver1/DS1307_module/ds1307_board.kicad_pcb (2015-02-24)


Board: 2 copper layers, 53.0 x 23.9 mm, 6 parts (1 on the bottom side), 7 nets.

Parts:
BT1: BATTERY; CR2032H
C1: C; C1
OSHW_COPPER_10MM: VAL**; OSHW_COPPER_10MM
P1: CONN_4; PIN_ARRAY_4x1
U1: DS1307; DIP-8__300_ELL
X1: CRYSTAL; QMONTRE

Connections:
5V: C1.1, P1.1, U1.8
GND: BT1.2, C1.2, P1.2, U1.4
unnamed: U1.2, X1.1
unnamed: BT1.1, U1.3
unnamed: U1.1, X1.2
SCL: P1.3, U1.6
SDA: P1.4, U1.5

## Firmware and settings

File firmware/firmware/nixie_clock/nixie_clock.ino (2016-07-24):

#include <avr/io.h>
#include <avr/wdt.h>
#include <Wire.h>
#include <Time.h>
#include <DS1307RTC.h>
#include <EEPROM.h>
#include <SoftwareSerial.h>

#include "pindef.h" 
#include "tube_control.h"

#include "RTC.h"
#include "clock.h"
#include "button.h"
#include "alarm.h"
#include "mp3.h"

extern int tube[8]; //This array records the data of all tubes
rtc_time_t time; //DS1307 time data

void setup()
{
  Serial.begin(9600);

  RTC_init();

  read_alarm_setting();
  mp3_init();

  pinMode(pin_font_a, OUTPUT);
  pinMode(pin_font_b, OUTPUT);
  pinMode(pin_font_c, OUTPUT);
  pinMode(pin_font_d, OUTPUT);
  
  pinMode(pin_font_left_dot, OUTPUT);
  pinMode(pin_font_right_dot, OUTPUT);
  
  pinMode(pin_tube_select_a0, OUTPUT);
  pinMode(pin_tube_select_a1, OUTPUT);
  pinMode(pin_tube_select_a2, OUTPUT);
  pinMode(pin_tube_select_a3, OUTPUT);
  
  pinMode(pin_play_button, INPUT);
  pinMode(pin_adjust_button, INPUT);
  pinMode(pin_mode_button, INPUT);

  enable_timer2();
}

void loop()
{
  RTC_read_time(&time);
  
  tube_digit_sort(tube, &time, clock_mode);

  check_hibernate_time(&time);
  
  check_alarm(&time);

  check_mp3_state();

  button_status_check();

  eeprom_hack_save();
}

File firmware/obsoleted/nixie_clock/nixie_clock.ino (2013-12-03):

#include <Arduino.h>
#include <Wire.h>

/* RTC Clock  */
#include <Time.h>
#include <DS1307RTC.h>

/* Music player module */
#include <Garan.h>
#include <SoftwareSerial.h>

#include "pin_def.h"
#include "display.h"
#include "clock_time.h"
#include "event.h"

/* Clock core */
clock_time clock;
/* Create the buttons */
searchButton btn_search(btn_search_pin, &clock);
adjustButton btn_adjust(btn_adjust_pin, &clock);
modeButton btn_mode(btn_mode_pin, &clock);

int isr_count = 0; //The counter of Timer

void setup()
{
    /* Setting the pin mode */
    //Fonts
    pinMode(font_pinA, OUTPUT);
    pinMode(font_pinB, OUTPUT);
    pinMode(font_pinC, OUTPUT);
    pinMode(font_pinD, OUTPUT);
    pinMode(dot_pin, OUTPUT);
    //Digits
    pinMode(digit_pinA, OUTPUT);
    pinMode(digit_pinB, OUTPUT);
    pinMode(digit_pinC, OUTPUT);
    //Display enable gate
    pinMode(display_enable_gate, OUTPUT);
    //Buttons
    pinMode(btn_search_pin, INPUT);
    pinMode(btn_adjust_pin, INPUT);
    pinMode(btn_mode_pin, INPUT);
    
    /* Enable the display */
    digitalWrite(display_enable_gate, HIGH);
    
    /* Initial the real time clock */
    setSyncProvider(RTC.get);
    
    /* Initial the serial for debugging */
    Serial.begin(115200);
    
    /* Initial the Timer1 */
    TCCR1A = 0x00; //Normal mode
    //No prescaling : CS12, CS11, CS10 = 0, 0, 1
    TCCR1B &= ~_BV(CS12);
    TCCR1B &= ~_BV(CS11);
    TCCR1B |= _BV(CS10);
    //Enable the overflow interrupt of Timer1
    TIMSK1 |= _BV(TOIE1);
    //Clear the counter of Timer1
    TCNT1 = 0;
}

ISR (TIMER1_OVF_vect)
{
    isr_count++;
    
    if(isr_count == 244) {
        clock.set_blink_time(clock.get_blink_time() + 1);
        
        //Reset the blink time for next duty
        if(clock.get_blink_time() > clock.blink_duty)
            clock.set_blink_time(0);
            
        //If the timer flag of the button is set to be enabled, start to increase the time 
        btn_search.hold_time_inc();
        btn_adjust.hold_time_inc();
        btn_mode.hold_time_inc();
                
        //Check time of the alarm
        if(clock.check_alarm_time() == true) {
            clock.play_music("alarm.mp3");
        }
        
        isr_count = 0;
    }
}

void loop()
{
      //Show the time on the display
      clock.display_time();
      
      //Check the status of the button and do the proper actions
      btn_search.button_click();
      btn_adjust.button_click();
      btn_mode.button_click();
}

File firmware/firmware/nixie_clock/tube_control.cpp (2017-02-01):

#include <Arduino.h>

#include "pindef.h"
#include "tube_control.h"
#include "RTC.h"
#include "clock.h"

int tube_select_table[8][4] = {{LOW, LOW, LOW, LOW}, {HIGH, LOW, LOW, LOW},
      {LOW, HIGH, LOW, LOW}, {HIGH, HIGH, LOW, LOW}, {LOW, LOW, HIGH, LOW},
      {HIGH, LOW, HIGH, LOW}, {LOW, HIGH, HIGH, LOW}, {HIGH, HIGH, HIGH, LOW}};

#if USE_HACKED_FONT == 0
int font_table[10][4] = {{LOW, LOW, LOW, LOW}, {HIGH, LOW, LOW, LOW},
      {LOW, HIGH, LOW, LOW}, {HIGH, HIGH, LOW, LOW}, {LOW, LOW, HIGH, LOW},
      {HIGH, LOW, HIGH, LOW}, {LOW, HIGH, HIGH, LOW}, {HIGH, HIGH, HIGH, LOW},
      {LOW, LOW, LOW, HIGH}, {HIGH, LOW, LOW, HIGH}};
#else
int font_table[10][4] = {{HIGH, LOW, LOW, HIGH}, {LOW, LOW, LOW, LOW},
      {HIGH, LOW, LOW, LOW}, {LOW, HIGH, LOW, LOW}, {HIGH, HIGH, LOW, LOW},
      {LOW, LOW, HIGH, LOW}, {HIGH, LOW, HIGH, LOW}, {LOW, HIGH, HIGH, LOW},
      {HIGH, HIGH, HIGH, LOW}, {LOW, LOW, LOW, HIGH}};
#endif

void tube_control(int tube_number, int tube_font)
{ 
  digitalWrite(pin_tube_select_a0, tube_select_table[tube_number][0]);
  digitalWrite(pin_tube_select_a1, tube_select_table[tube_number][1]);
  digitalWrite(pin_tube_select_a2, tube_select_table[tube_number][2]);
  digitalWrite(pin_tube_select_a3, tube_select_table[tube_number][3]);
  
  if(tube_font == EMPTY_FONT) {
    //Let K155ID1 input over range (Always off)
    digitalWrite(pin_font_a, LOW);
    digitalWrite(pin_font_b, HIGH);
    digitalWrite(pin_font_c, LOW);
    digitalWrite(pin_font_d, HIGH);
  } else {
    digitalWrite(pin_font_a, font_table[tube_font][0]);
    digitalWrite(pin_font_b, font_table[tube_font][1]);
    digitalWrite(pin_font_c, font_table[tube_font][2]);
    digitalWrite(pin_font_d, font_table[tube_font][3]);
  }
}

void set_tube_brightness(int brightness) /* brightness value should between 0 to 100 */
{
  //analogWrite(pin_brightness, brightness * 255 / 100);
  digitalWrite(pin_brightness, HIGH);
}

void tube_digit_sort(int tube_font[8], rtc_time_t *time, int clock_mode)
{ 
  switch(clock_mode) {
    case DATE_MODE:
      //Year
      tube_font[TUBE_7] = time->year / 1000;
      tube_font[TUBE_6] = (time->year / 100) % 10;
      tube_font[TUBE_5] = (time->year / 10) % 100;
      tube_font[TUBE_4] = time->year % 10;
      //Month
      tube_font[TUBE_3] = time->month / 10;
      tube_font[TUBE_2] = time->month % 10;
      //Day
      tube_font[TUBE_1] = time->day / 10;
      tube_font[TUBE_0] = time->day % 10;
      break;

    case TIME_MODE:  
      //Hour
      tube_font[TUBE_7] = time->hour / 10;
      tube_font[TUBE_6] = time->hour % 10;
      //Minute
      tube_font[TUBE_4] = time->minute / 10;
      tube_font[TUBE_3] = time->minute % 10;
      //Second
      tube_font[TUBE_1] = time->second / 10;
      tube_font[TUBE_0] = time->second % 10;
      //Empty
      tube_font[TUBE_5] = EMPTY_FONT;
      tube_font[TUBE_2] = EMPTY_FONT;
      break;
  }
}

void sort_tube_digit_for_music(int tube_font[8], int song)
{
  tube_font[TUBE_7] = 0;
  tube_font[TUBE_6] = 0;
  tube_font[TUBE_5] = 0;
  tube_font[TUBE_4] = 0;
  
  tube_font[TUBE_3] = song / 1000;
  song %= 1000;
  
  tube_font[TUBE_2] = song / 100;
  song %= 100;
  
  tube_font[TUBE_1] = song / 10;
  song %= 10;

  tube_font[TUBE_0] = song;
}

void tube_hibernate()
{
  digitalWrite(pin_tube_select_a0, HIGH);
  digitalWrite(pin_tube_select_a1, HIGH);
  digitalWrite(pin_tube_select_a2, LOW);
  digitalWrite(pin_tube_select_a3, HIGH);
}

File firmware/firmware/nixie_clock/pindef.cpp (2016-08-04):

#include <Arduino.h>

#include "pindef.h"

//K155IDI
int pin_font_a = 13, pin_font_b = 12, pin_font_c = 11, pin_font_d = 10;

int pin_font_left_dot = A1, pin_font_right_dot = A0;

//HEF4028
int pin_tube_select_a0 = A3, pin_tube_select_a1 = 7, pin_tube_select_a2 = 6, pin_tube_select_a3 = 5;

int pin_brightness = 9;

//Buttons
int pin_play_button = 4, pin_adjust_button = 3, pin_mode_button = 2;

//MP3
int mp3_rx = 8, mp3_tx = 9, mp3_state = 3;

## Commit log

2013-11-10 support the mode switch button
    *Also fixed the date issue in function sort_to_digit()
    [nixie_clock.ino]
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2013-11-10 added the missing debug.cpp file
    [debug.cpp]
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2013-11-12 added the dot point at the time mode and fixed some bugs
    (1)Added the dot point related code
    (2)Improved the blur issue which cause on seven segment display
    (3)Fixed the bug that the mode button is not able to switch to other digits on setting mode
    [display.cpp, nixie_clock.ino]
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2013-11-13 implemented the basic setting action of the time
    *The code need to add more judgements or will cause some errors
    [event.cpp]
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2013-11-20 created the circuit project and added arduino-uno in libraries
    [nixie-clock.sch]
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2013-11-21 support better digit blink implemented by using timer
    *Support multiple digits to blink at the same time (Also improve the writing skill)
    *Added clock test code to test while the DS1307 time chip is broken
    [nixie_clock.ino]
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2013-11-21 added 4 digits 7 segments display in the component library
    [nixie-clock.sch]
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2013-11-22 fixed the wrong kicad command in readme
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2013-11-27 added the time structure and support to switch to the alarm mode
    (1)Replace the time related variable to time structure.
    (2)Support switching the mode to the alarm mode, but not implement the detail yet.
    [event.cpp]
2013-12-03 imported the music player module
    *FIXME:The functions is basiclly finished, but it doesn't work
    *Implemented the alarm time checking function
    [debug.cpp, nixie_clock.ino]
2013-12-03 fixed the music broadcast issue
    *The alarm can use the music function from now
    (1)FIXME:The function play_music() still have some problems need to improve
    (2)Replaced the serial event for testing the music function
    [debug.cpp, nixie_clock.ino]
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2014-02-01 added the basic circuit of the nixie tube power supply
    [power-supply.sch]
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2014-02-01 power_supply: filled the value in all components
    [power-supply.sch]
2014-02-01 power_supply: replaced the components of Vcc/Ground
    [power-supply.sch]
2014-02-01 power_supply: created the net file
    [power-supply.sch]
2014-02-01 power_supply: set the package type of all components
    [power-supply.brd]
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2014-02-02 Remove some rubbish kicad project files
    [power-supply.brd]
2014-02-02 power_supply: completed the component type selection
    *Import the TO-247 footprint into the project setting
    *Updated the net file
    *Created the PCB board file
    [power-supply.kicad_pcb, power-supply.sch]
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2014-02-03 power_supply: generated the routing files
    [power-supply.dsn]
2014-02-03 power_supply: added batteries and connecters
    [power-supply.sch]
2014-02-03 power_supply: completed the nixie tube power supply circuit
    [power-supply.kicad_pcb]
2014-02-03 power_supply: increased the size of the track line
    [power-supply.dsn, power-supply.kicad_pcb]
2014-02-03 power_supply: added some space between two track lines
    [power-supply.kicad_pcb]
2014-02-04 power_supply: added two resistors into the circuit
    [power-supply.dsn, power-supply.kicad_pcb, power-supply.sch]
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2014-02-04 power_supply: imported the OSHW logo and adjusted the route
    [power-supply.kicad_pcb]
2014-02-07 control_board: removed the unused test circuit
    [nixie-clock.sch]
2014-02-07 control_board: added the basic ATMega328p circuit
    [nixie-clock.sch]
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2014-02-11 power_supply: expanded the pad size
    [power-supply.kicad_pcb]
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2014-02-16 power_supply: fixed the wrong TO-92 ECB footprint issue
    [power-supply.dsn, power-supply.kicad_pcb, power-supply.sch]
2014-06-14 Finish the basic nixie tube control circuit
    [nixie-clock.sch]
2014-06-14 Add the button circuit into the control board
    [nixie-clock.sch]
2014-06-22 Fix the HEF42028 circuit (control board, to anode pin)
2014-06-22 Control board: add the mp3 tx/rx port circuit
    [nixie-clock.sch]
2014-06-23 Control board: connect the wire of nixie tube's right dot
    [nixie-clock.sch]
2014-06-23 Control board: connect the wire of the bluetooth module
    [nixie-clock.sch]
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2014-06-27 Control board: Clear the messy circuit, and modularize the AC adapter
    [nixie-clock.sch]
2014-06-27 Control board: Modularize the circuit of nixie tube power supply (170v)
    [nixie-clock.sch]
2014-06-27 Control board: Modularize the circuit of buttons
    [nixie-clock.sch]
2014-06-27 Control board: Modularize the circuit of mp3 module
    [nixie-clock.sch]
2014-06-27 Control board: Modularize the circuit of bluetooth and fix mp3 module's circuit
    [nixie-clock.sch]
2014-06-27 Control Board: Fix the wrong pin direction of "TLP521"
2014-06-27 Control board: Modularize the circuit of reset button and crystal
    [nixie-clock.sch]
2014-06-27 Control board: Connect the power to the Atmega328 microcontroller
    [nixie-clock.sch]
2014-06-27 Control board: Modularize the circuit of nixie tube anode pin
    [nixie-clock.sch]
2014-06-27 Control board: Modularize the circuit of nixie tube cathode pin
    [nixie-clock.sch]
2014-06-27 Control board: Create the circuit for DS1307 time module
    [nixie-clock.sch]
2014-06-27 Control board: Fill in the value of resistor
    [nixie-clock.sch]
2014-06-27 Control board: Create the circuit for FTDI
    [nixie-clock.sch]
2014-06-30 Add some no connect flag
    [nixie-clock.sch]
2014-06-30 Control board: Remove a connecter
    [nixie-clock.sch]
2014-06-30 Control board: Annoate the circuit
    [nixie-clock.sch]
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2014-07-01 Control board: Fix the wrong package type of component
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2014-07-01 Control board: Add the missing pcb file
    [nixie-clock.kicad_pcb]
2014-07-01 Control board: Create the PCB zone
    [nixie-clock.kicad_pcb]
2014-07-01 Control board: Connect 170v power with TLP521
    [nixie-clock.sch]
2014-07-01 Control board: Adjust the wire
    [nixie-clock.kicad_pcb]
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2014-07-01 Control board: Add the left dot control circuit
    [nixie-clock.sch]
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2014-07-02 COntrol board: Fix the mp3 player voltage divided circuit error
    [nixie-clock.sch]
2014-07-02 Control board: Fix the wrong pin of "K155ID1"
2014-07-02 Control board: Arrange the circuit and re-autoroute the PCB board
    [nixie-clock.dsn, nixie-clock.kicad_pcb]
2014-07-02 Control Board: Rearrange the position of the PCB board
    [nixie-clock.kicad_pcb]
2014-07-02 Control board: Add two 2*1 pin array for 5v power
    [nixie-clock.dsn, nixie-clock.kicad_pcb, nixie-clock.sch]
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2014-07-02 DS1307 board: Set the package type of all components
    [ds1307_board.sch]
2014-07-02 DS1307 board: Finish design and route the board
    [ds1307_board.dsn, ds1307_board.kicad_pcb]
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2014-08-03 COntrol board: Fix the pad shape
    [nixie-clock.kicad_pcb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]
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2014-08-04 Update the nixie-clock.kicad_pcb to the Kicad EDA4 format
    [nixie-clock.kicad_pcb]
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2015-02-16 Control board: Remove the coper zone and adjust the track line
    [nixie-clock.kicad_pcb]
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2015-02-17 Control board: Adjust track line, pad size and via size
    [nixie-clock.kicad_pcb]
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2015-02-18 DS1307 board: Remove the coper zone, adjust the track line
    [ds1307_board.kicad_pcb]
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2015-02-24 DS1307 module: Optimize the layout to only single side
    [ds1307_board.kicad_pcb]
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2015-04-17 Control board: Fix the missing net
    [nixie-clock.kicad_pcb, nixie-clock.sch]
2015-04-17 Control board: Fix the FTDI Rx net and optimize some route
    [nixie-clock.kicad_pcb, nixie-clock.sch]
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2015-04-19 Control board: Fix missing not optimized track line
    [nixie-clock.kicad_pcb]
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2015-05-16 Control board: Adjust the size of via drill
    [nixie-clock.kicad_pcb]
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2015-05-24 Firmware: Finish scanning display with the correct time
    [RTC.cpp, clock.cpp, nixie_clock.ino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]
2015-05-25 Firmware: Fix time mode tube 2 and 5 over bright issue
    [clock.cpp, tube_control.cpp]
2015-05-26 Firmware: Replace the old RTC library with new one
    [RTC.cpp]
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2015-11-26 [All in one]Select resister and power jack's footprint
    [RTC.sch, audio.sch, nixie_control.sch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]
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2016-05-13 Fix mode change error
    [button.cpp, clock.cpp]
2016-05-13 Fix EEPROM and alarm setting
    [alarm.h, nixie_clock.ino, pindef.cpp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]
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2016-06-01 Fix the battery set
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2016-07-05 Fix RTC to be more accurate
    [RTC.cpp, clock.cpp, nixie_clock.ino]
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2016-07-31 Commertial designed new board, fix multipe bugs from last version
    [RTC.sch, audio.sch, display.sch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]
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2016-07-31 Fix firmware multiple bugs
    [serial.cpp]
2016-08-03 Fix music random play, button debounce and hibernation check
    [alarm.h, button.cpp, clock.cpp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]
2016-08-04 Fix hibernation time check
    [clock.cpp]
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2016-08-04 Fix Software serial ISRT priority issue
    [button.cpp, pindef.cpp, serial.cpp]
2016-08-07 Fix loop play check
    [serial.cpp]
2016-08-07 Layout need to be arranged, scheme is finished
    [RTC.sch, audio.sch, display.sch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]
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2017-02-01 Fix freecad
    [cad.fcstd]
2017-02-01 Fix PCB board
    [RTC.sch, nixie_control.sch, nixie_control_board.kicad_pcb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]
2017-02-01 Fix display board button
    [display.sch, nixie_control_board.kicad_pcb]
2017-02-02 Fix board errors
    [RTC.sch, nixie_control.sch, nixie_control_board.kicad_pcb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]
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2018-04-27 Fix compiliation issue of new version Arduino
    [RTC.cpp]
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
